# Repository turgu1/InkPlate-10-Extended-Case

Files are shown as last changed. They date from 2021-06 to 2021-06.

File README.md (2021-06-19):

# InkPlate-10-Extended-Case

This is a change to the current InkPlate-10 case to add a small electronic board with push buttons below the mainboard. To do it, I took the original design from e-Radionica and extended a side of it so the original portion of the case remains unchanged. The `Mechanical CAD` folder contains the complete STEP format design as well as the STL files ready for 3D printing. The `Electronics` folder contains the Gerber files for the preparation of the buttons' pc-board, as well as the schematic in PDF. This is the same pc-board as for the InkPlate-6-Extended-Case. I have used **FreeCAD** and **KiCAD** to complete this project.

- For the STL files, dimensions are in millimeters. 
- Six buttons must be printed as well as the top and bottom casing. The buttons may have to be adjusted in size depending on the 3D printing results.
- The connection with the MCU23017 is done using wirewrap wires (or a flat cable) that are soldered at both ends using the following configuration (beware that the corresponding buttons numbers are inverted in the sequence):

```
   On the   |     On the     | Corresponding 
Buttons PCB | InkPlate Board |    Button
------------+----------------+---------------
            |                |
   Pin 1    |      GND       |
   Pin 2    |      GPB2      |      U6
   Pin 3    |      GPB3      |      U3
   Pin 4    |      GPB4      |      U5
   Pin 5    |      GPB5      |      U1
   Pin 6    |      GPB6      |      U4
   Pin 7    |      GPB7      |      U2
```

- On the buttons' pc-board, the squared pad is pin 1.
- On the buttons' pc-board, there is no through-hole, just pads on the surface to solder the wires. This is to ensure that the board will remains flat at the bottom of it's location in the casing.
- The three touch pads on the InkPate-10 pc-board must be disabled, the corresponding signals from the MCU23017 must be diverted to the GPBx pin holes on the main pc-board. This is done by desoldering the current jumpers and soldering them back on the other side. They are located under the following labeling on the board: "Touch pads".
- The GPIOB I/O bits of the MCU23017 corresponding to the GPB2 through GPB7 pins must have their internal pull-up resistor enabled.
- The buttons' pc-board must be of a standard height (1.6 mm). This to ensure proper spacing for the printed buttons. The board must be 'glued' at the bottom of the main casing using two-sided scotch tape. An alternative would be to use a very small amount of hot glue on the 4 corners on the top of the buttons' pc-board. This is to permit easy removal in case of problems. I found that if the printed buttons are tight enough, no glue or tape is required as the board will be maintained in place by the printed buttons.
- The button switches' part number is C&K PTS526 SK15 SMTR2 LFS 5.2x5.2x1.5 mm. They are very common (For exemple, Mouser part # 611-PTS526SK15SMR2L, Digikey Part # CKN12221-1-ND, or other manufacturers equivalent). The 1.5 mm height is important to insure proper spacing for the printed buttons.

The original licensing from e-Radionica remains GPL-3 for their design as well as all supplied files in this project.

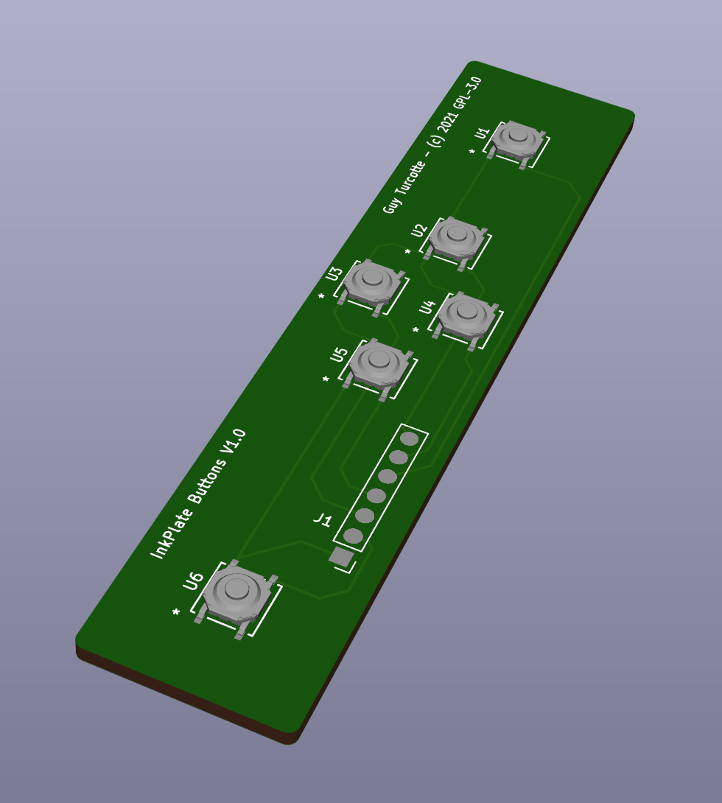
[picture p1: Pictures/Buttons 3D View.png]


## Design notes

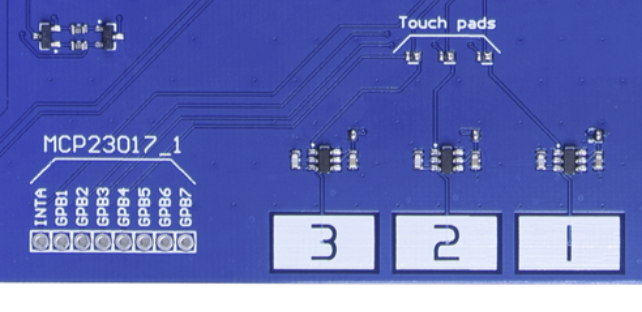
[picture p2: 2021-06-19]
Pictures/Touch pads jumpers and GPBx pin holes.png

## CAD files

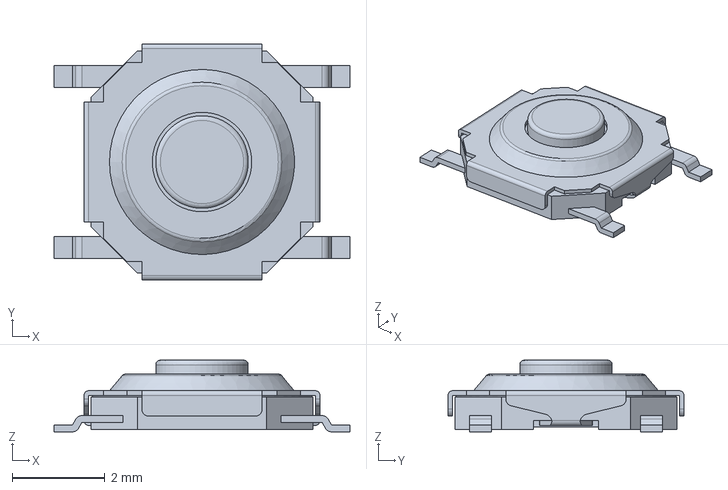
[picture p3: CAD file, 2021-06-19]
Electronics/KiCAD/Parts/3D/PTS526SK15SMTR2LFS.stp
6.40 x 5.10 x 1.55 mm

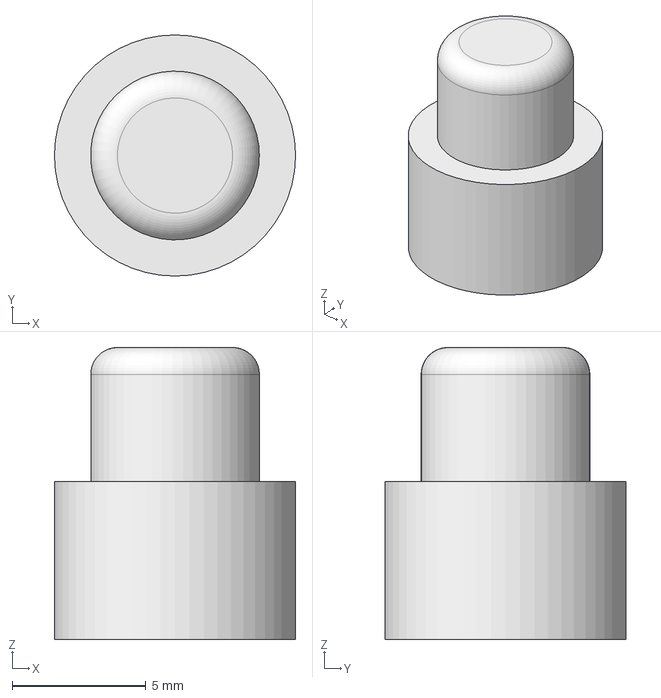
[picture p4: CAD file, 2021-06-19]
Mechanical CAD/FreeCAD/button.FCStd
9.00 x 9.00 x 10.9 mm

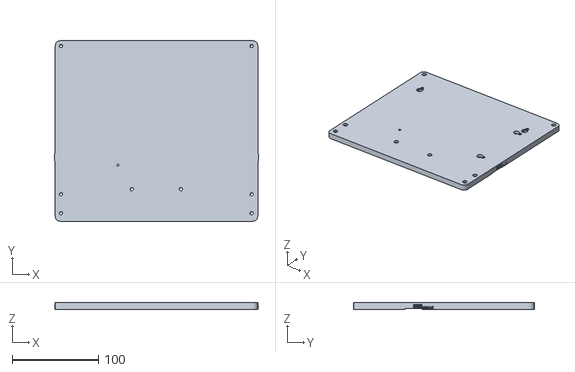
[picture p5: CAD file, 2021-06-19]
Mechanical CAD/Inkplate-10-Bottom-V1.0.stl
236.6 x 209.5 x 7.80

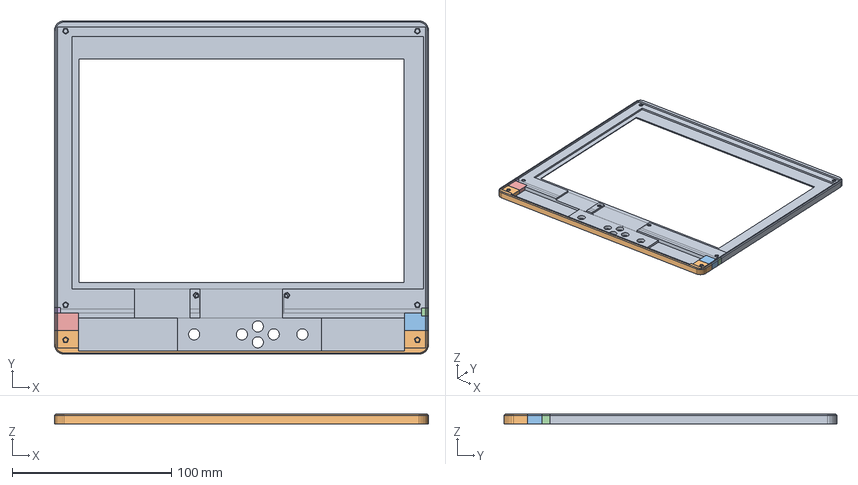
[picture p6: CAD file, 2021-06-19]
Mechanical CAD/FreeCAD/top.FCStd
235.0 x 209.5 x 6.20 mm
Slice.1

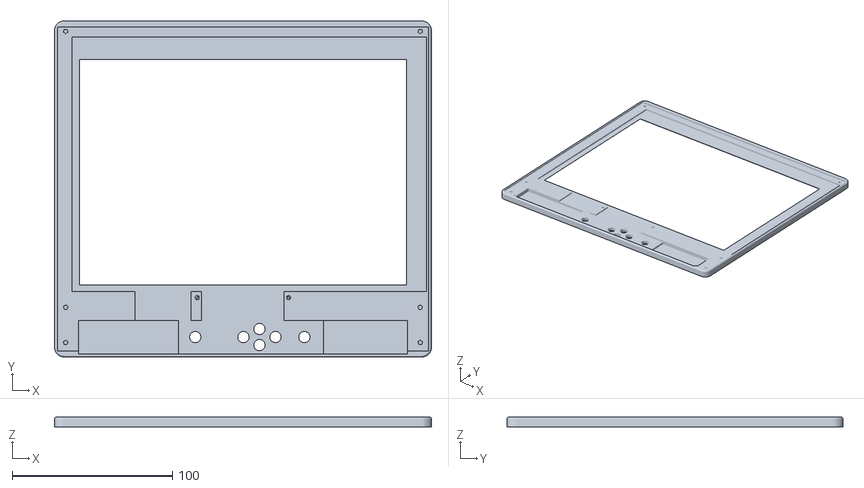
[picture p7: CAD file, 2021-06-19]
Mechanical CAD/Inkplate-10-Top-V1.0.stl
235.0 x 209.5 x 6.20

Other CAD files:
Mechanical CAD/Inkplate-10-Button-V1.0.stl

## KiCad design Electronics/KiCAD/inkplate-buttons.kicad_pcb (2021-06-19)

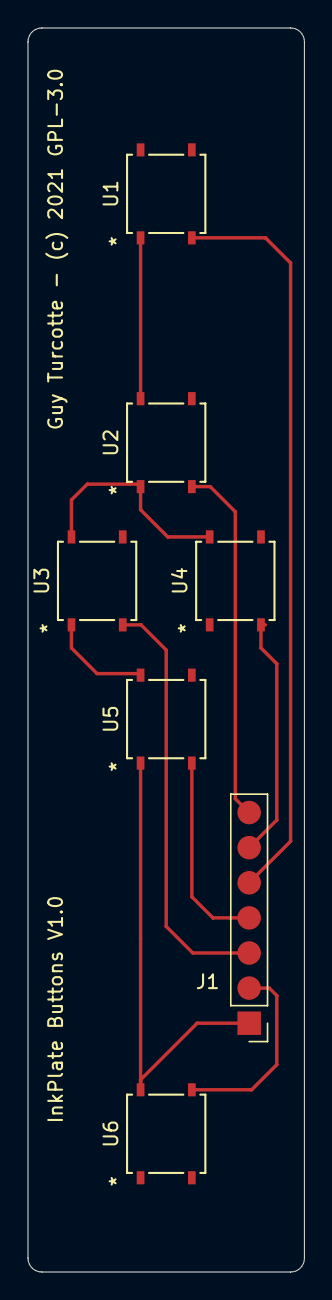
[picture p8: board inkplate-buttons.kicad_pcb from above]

Board: 2 copper layers, 20.0 x 90.0 mm, 7 parts (0 on the bottom side), 10 nets.

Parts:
J1: J1; PinHeader_1x07_P2.54mm_Vertical
U1: U1; PTS526 SK15 SMTR2 LFS
U2: U2; PTS526 SK15 SMTR2 LFS
U3: U3; PTS526 SK15 SMTR2 LFS
U4: U4; PTS526 SK15 SMTR2 LFS
U5: U5; PTS526 SK15 SMTR2 LFS
U6: U6; PTS526 SK15 SMTR2 LFS

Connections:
unnamed: J1.1, U5.1, U6.2
unnamed: J1.2, U6.4
unnamed: J1.3, U3.3
unnamed: J1.4, U5.3
unnamed: J1.5, U1.3
unnamed: J1.6, U4.3
unnamed: J1.7, U2.3
unnamed: U1.1, U2.2
unnamed: U2.1, U3.2, U4.2
unnamed: U3.1, U5.2

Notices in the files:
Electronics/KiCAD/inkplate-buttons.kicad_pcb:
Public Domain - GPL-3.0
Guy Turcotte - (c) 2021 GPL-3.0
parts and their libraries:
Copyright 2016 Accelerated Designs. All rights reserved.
